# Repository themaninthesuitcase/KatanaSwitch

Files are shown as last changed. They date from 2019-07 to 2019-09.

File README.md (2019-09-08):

# KatanaSwitch

**KatanaSwitch** is the Arduino firmware code for a basic 4 button foot switch for the BOSS Katana 50 amplifer.

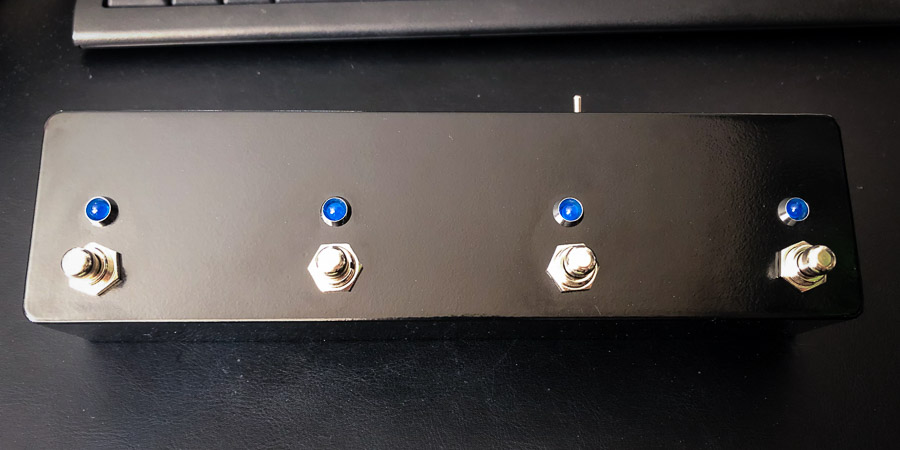
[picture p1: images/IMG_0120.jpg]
Completed Foot Switch using 1032L enclosure


Normally a 2 button latching foot-switch is used, one switching channels and the other switching banks. Say you wanted to change from A-1 to B-2 this would require both buttons to be toggled, one to swap channels and the other to swap banks.  This pedal features 4 momentary switches giving access to all 4 channels via a single button press.

The Katana 50 foot-switch jack is a TRS (Stereo) connection with Tip switching the channel and Ring switching the bank.  To enable foot-switching simply insert a TRS cable into the foot switch jack.

*Note: This will also work with the Katana 100 line but the GA-FC foot-switch will do the same off the shelf.*

## Licensing

This project is considered to be [Creative Commons Attribution-NonCommercial-ShareAlike][cc].  Basically you can make them, but don't sell them.

## Channel switching

The channels and banks are selected by shorting either the tip or ring to the Sleeve.  The map of channels to connections is below, with HIGH meaning the connection is shorted to the sleeve and LOW meaning open circuit.

| Channel | Tip | Ring |
|---|-----|---|
| A-1 | HIGH | HIGH |
| A-2 | HIGH | LOW |
| B-1 | LOW | HIGH |
| B-2 | LOW | LOW |

If you connect a TRS cable to the amp end only then it will switch to B-2 as the amp detects the jack but the connections are open.

## Circuit

The firmware assumes the below circuit.  If you create your own then you may need to update the pins used for the switches in and the LED outs.  These are all defined in constants at the top of the file.

*Note: On the Arduino Nano used pins A6 and A7 are analogue input only and will not function in digital mode as either an input or output.*

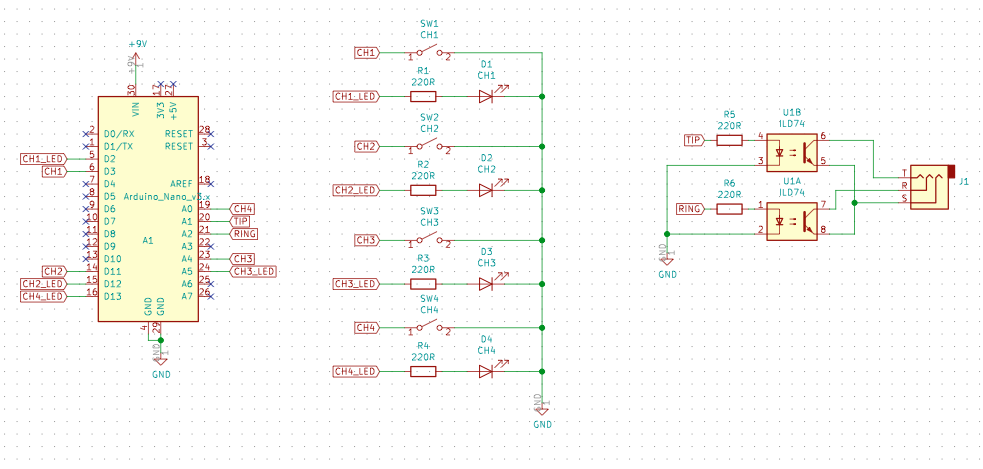
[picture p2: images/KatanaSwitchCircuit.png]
Circuit Diagram


### Bill Of Materials

 * **A1** Arduino Nano v3
 * **IC1** ILD74 Optocoupler
 * **J1** 1/4" TRS (Stereo) jack socket
 * **R1** 220Ω - Current limited Resistor (CLR) Channel 1*
 * **R2** 220Ω - CLR Channel 2
 * **R3** 220Ω - CLR Channel 3
 * **R4** 220Ω - CLR Channel 4
 * **R5** 220Ω - CLR Optocoupler
 * **R6** 220Ω - CLR Optocoupler

**For resistors R1-R4 you may need to change the value dependent on your chosen LEDs.**  Use an [LED Calculator][ledcalc], the supply voltage will be 5V, the forward voltage and current will depend on your LED, check the datasheet.

A PCB design is available for convenience as used in my own pedal.  This is 76x36mm in size, so is a bit awkward to fit in some enclosures with the switches and LEDs.  This is something I may address in a future iteration.

The files to make a board can be found in the ```/GerberFiles``` folder.  I used [JLCPCB] in China to manufacture the boards.

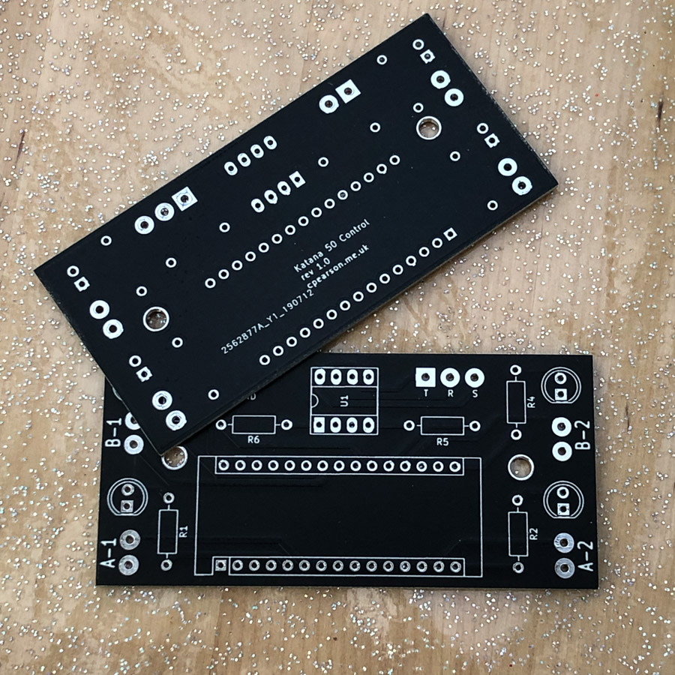
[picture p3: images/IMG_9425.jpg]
JLCPCB made boards


The PCB was laid out with a 1590BB in mind.  My build used a [1032L], though a [Hammond 1590BX][1590bx] is similar in size, though shallower, and will probably work well too if care is taken to fit the PCB.  Using a 4 in line enclosure you will either need to adjust the output pin order, or you will have to use some non-optimal wiring.  See the [Layout-1032L][1032L-branch] branch for the changes I used.

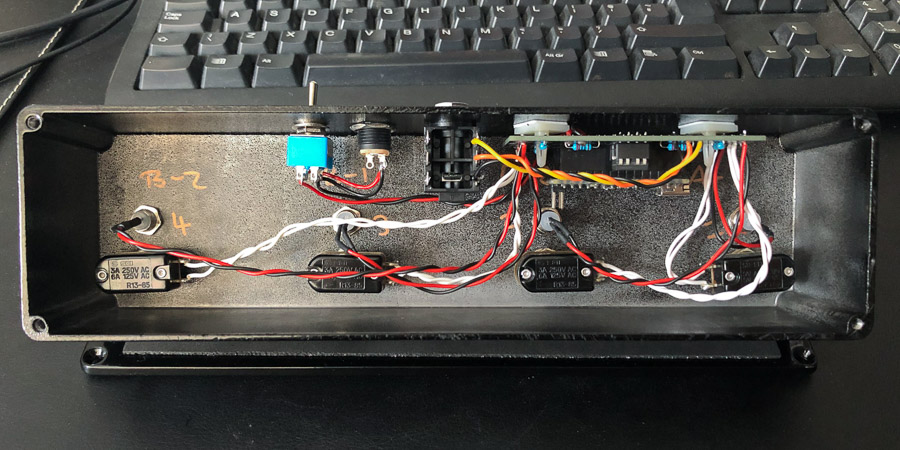
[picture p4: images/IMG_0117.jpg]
Internals of my 1032L build


## Known Issues

 * LED for Channel B-2 will remain on dimly at all times.  This is because I used pin 13 which is the pin for the built in LED.  If revised in future I will change this to another pin.

[jlcpcb]: https://jlcpcb.com/
[ledcalc]: http://led.linear1.org/1led.wiz/
[cc]: https://creativecommons.org/licenses/by-nc-sa/4.0/
[1590bx]: http://www.hammondmfg.com/pdf2/1590BX.pdf
[1032L]: http://www.timetravelaudio.co.uk/shop/components/powder-coated-die-cast-aluminium-enclosures/
[1032L-branch]: https://github.com/themaninthesuitcase/KatanaSwitch/tree/Layout-1032L

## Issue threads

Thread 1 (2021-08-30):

Priority between the built-in buttons and the footswitch ?

MH-guitar, 2021-08-30:
Hello,

Having purchased recently a Katana Mk2 50 amp, I've read about your project with great interest. I would consider making a similar project, but using directly a Attiny2313 microcontroller and almost the same schematics as you.

I've got some questions about the priority between the amp built-in buttons and any external footswitch.

- When a footswitch is connected, can we still use the built-in buttons to setup a new configuration and store it in a channel for example ?
- What happens when you select a channel / bank through the built-in buttons, then through a footswitch ?
- Does the amp check the changes of states on the jack to change to another channel / bank ?

Many thanks and best regards from Switzerland.
Marc

themaninthesuitcase, 2021-08-31:
I'll need to confirm with the amp which is not currently set up but as I recall:

- Yes you can use the amp top buttons, but the foot switch won't know that. To save changes you have to use the amp, the foot switch can't do it.
- If you select say A1 via the foot switch the press B on the amp it will swap at the amp end.  The foot switch can't see this and stays at A1.  If you then press B2 on the foot switch the amp will switch to B2.  Basically "last press wins".
- Not sure what you mean, but the jack input tells the amp what to switch to.  If you set it to "bank A patch 2" then the jack is locked to that and when the amp sees change that it switches.  Then amp will only switch on a change at the jack meaning if you want to use the panel buttons you can and it won't suddenly swap back.  At least that's what I saw when testing as I only tended to use the switch OR the panel, not really both.

MH-guitar, 2021-09-01:
Hello Chris,

Many thanks for your thorough answers.

Your answer to my 3rd question is exactly what I was considering: the amp doesn't switch back and forth between the channel / bank selected from the footswitch and the ones selected from the buttons.

Best regards.
Marc

MH-guitar, 2022-10-11:
Hello,
Few weeks ago, I've completed my DIY footswitch for the Katana Mk2 50.
My project has the following features:
* Based on a Attiny 45 microcontroller directly programmed in C, a dual optocoupler to isolate the amp, a couple of resistance and 3 leds.
* A single push button to loop over the banks and channels in the following order: A1, A2, B1, B2.
* 3 leds indicating the status with the same convention as the leds on the amp: 2 leds for channels 1/2, 1 led for bank (off: A, blinking: B).
* Enclosure built with old Mecano parts.
Please find attached pictures of the footswitch and here's a short video showing it: https://youtube.com/shorts/rrMnU0gCXO8?feature=share
Many thanks for having inspiring me to build my own footswitch. Best regards from Switzerland.

Marc-Henri

themaninthesuitcase, 2022-10-17:
Looks awesome! The AtTiny is probably a much better platform for something like this as it helps keep things small, and it doesn't really need much compute.

Closed 2021-09-01.

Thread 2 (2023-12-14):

There is a simple way to do this.

infinitekh, 2023-12-14:
I saw this project yesterday and was impressed.
However, while working today, I learned about 74hc138d, a 3-to-8 line decoder/demultiplexer.

This project seemed to be exactly the opposite of this, so I looked into it and found that an IC called **74LS148** works in the exact opposite direction.

Since it's just a logic circuit, it seems like some kind of ASIC already existed.

I'm sorry I'm not an English speaker. I got help from Google Translator.

themaninthesuitcase, 2023-12-14:
I have only skim read the data sheets but I dont think you could. Or at least not without a lot of supporting circuitry to latch each footswitch, transistors to drive the loads etc.  Given the complexity and part count a £3 Arduino is over kill but simple.

infinitekh, 2023-12-15:
I see. Thank you for your reply. That was beginner's nonsense.
Now that I think about it, you're right.
Excuse me for bothering you.

Closed 2023-12-14.

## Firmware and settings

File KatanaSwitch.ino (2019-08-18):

//
//  KatanaSwitch.ino
//  KatanaSwitch
//
// Firmware for arduino based channel switching pedal for the
// the Boss Katana 50 Amplifer.
//
//  Created by Chris Pearson on 03/01/2019.
//  Copyright © 2018 Chris Pearson. All rights reserved.
//

// Switching Operations:
// Tip  : Switches between CH1 and CH2
// Ring : Switches between BANK A and BANK B

#define BAUD_RATE 9600

#define BTN_A1 3
#define BTN_A2 11
#define BTN_B1 A4
#define BTN_B2 A0

#define LED_A1 2
#define LED_A2 12
#define LED_B1 A5
#define LED_B2 13

const int debounceMillis = 10;

const int channels = 4;
int lastChannel = 0;

// Pin out Configuration
// NOTE: Analogue pins A6 and A7 are Analog input only on a Nano, we can't really use them here
// 0 based channels are used in the code for simplicity.
// 0 = A-1, 1 = A-2, 2 = B-1 & 3 = B-2
const int buttonPins[channels] = {BTN_A1, BTN_A2, BTN_B1, BTN_B2};
const int ledPins[channels] = {LED_A1, LED_A2, LED_B1, LED_B2};
const int channelPin = A1; // TIP
const int bankPin = A2;    // RING

int channelSettings[channels][2] = {
    // Channel, Bank
    // (Tip, Ring)
    {HIGH, HIGH}, // A1
    {LOW, HIGH},  // A2
    {HIGH, LOW},  // B1
    {LOW, LOW}};  // B2

void setup()
{
  Serial.begin(BAUD_RATE);
  Serial.print("Booting...\n\n");

  // Initialise all the pins, buttons to INPUT_PULLUP, LEDs to OUTPUT
  for (int i = 0; i < channels; i++)
  {
    int led = ledPins[i];
    int button = buttonPins[i];

    // Log some stuff that's usefull when debugging
    Serial.print("CHANNEL: "); Serial.print(i + 1); Serial.print("\n");
    Serial.print("BUTTON PIN: "); Serial.print(button); Serial.print("\n");
    Serial.print("LED PIN: "); Serial.print(led); Serial.print("\n");

    pinMode(button, INPUT_PULLUP); // Set button pins to an input

    pinMode(led, OUTPUT);    // Set the led pin to an output
    digitalWrite(led, HIGH); // Flash them for a pretty start sequence.
    delay(200);
    digitalWrite(led, LOW); // Make sure the LED is off we are done.
  }

  // Setup the channel and bank pins
  pinMode(channelPin, OUTPUT);
  digitalWrite(channelPin, LOW);
  pinMode(bankPin, OUTPUT);
  digitalWrite(bankPin, LOW);

  // Default to the first channel
  setChannel(0);

  Serial.print("Boot completed.\n\n");
}

// Demo mode!
// void loop(){
//   setChannel(0);
//   delay(1000);

//   setChannel(1);
//   delay(1000);

//   setChannel(2);
//   delay(1000);

//   setChannel(3);
//   delay(1000);

// }
void loop()
{
  // Check all the buttons for a press
  for (int i = 0; i < channels; i++)
  {
    // Using INPUT_PULL up so HIGH is off, LOW is on.
    if (digitalRead(buttonPins[i]) == LOW)
    {
      // Super basic debouce as the complexity of managing multiple inputs isn't necessary.
      // This is blocking but it shouldn't matter much as we're not checking lots of stuff.
      delay(debounceMillis);

      if (digitalRead(buttonPins[i]) == LOW)
      {
        // Guard against changing to the same channel
        if (i != lastChannel) setChannel(i);

        // If one button is high don't bother testing the rest
        // only one can be on at any one time.
        break;
      }
    }
  }
}

void setChannel(int newChannel)
{
  Serial.print("Changing to channel: "); Serial.print(newChannel); Serial.print("\n");
  Serial.print("Previous channel: "); Serial.print(lastChannel); Serial.print("\n");

  int lastLed = ledPins[lastChannel];
  int newLed = ledPins[newChannel];

  // Update the channel LEDs
  // Turn the last channel LED off
  digitalWrite(lastLed, LOW);

  // Save the new the last channel for the next time we change
  lastChannel = newChannel;

  // Update the output as per the channel selected
  setOutputs(newChannel);

  // Turn on the new channel LED
  digitalWrite(newLed, HIGH);

  Serial.print("Channel changed.\n");
}

void setOutputs(int channel)
{
  digitalWrite(channelPin, channelSettings[channel][0]);
  digitalWrite(bankPin, channelSettings[channel][1]);
}

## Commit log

2019-06-25 Complete theoretical draft of code.
    Sets pins to what should be correct for final version.
    [KatanaSwitch.ino]
2019-06-27 Add comments documenting the switching at the jack
2019-07-11 Switching logic was inversed to my assumption
    The boss katana needs HIGH tip for ch1 and HIGH ring for bank A,
    I assumed the other way round.
2019-07-17 Add initial Readme and Gerbers
    [KatanaSwitch-B.Cu.gbr, KatanaSwitch-B.Mask.gbr, KatanaSwitch-B.Paste.gbr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]
2019-07-17 Corrects resistance of R5/6
2019-07-17 Adds BOM and other minor changes.
2019-08-18 Move pin assignments into defines
    This allows easier re-ordering of channels if the wiring does not match
    the screen printing on the board.
